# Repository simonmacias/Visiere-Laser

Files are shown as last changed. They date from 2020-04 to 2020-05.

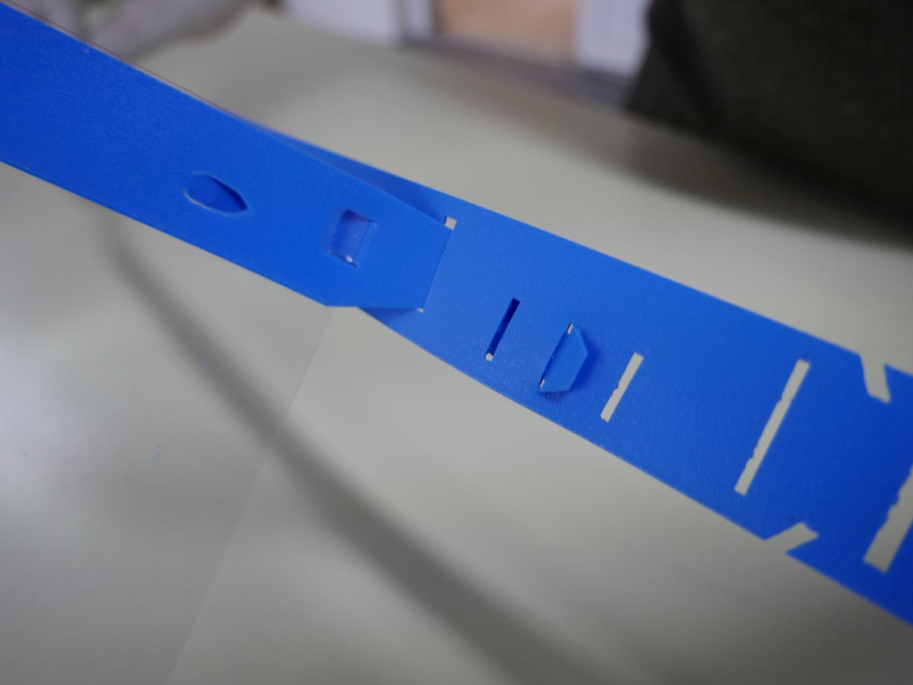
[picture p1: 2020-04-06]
VISI70/Images/2.JPG

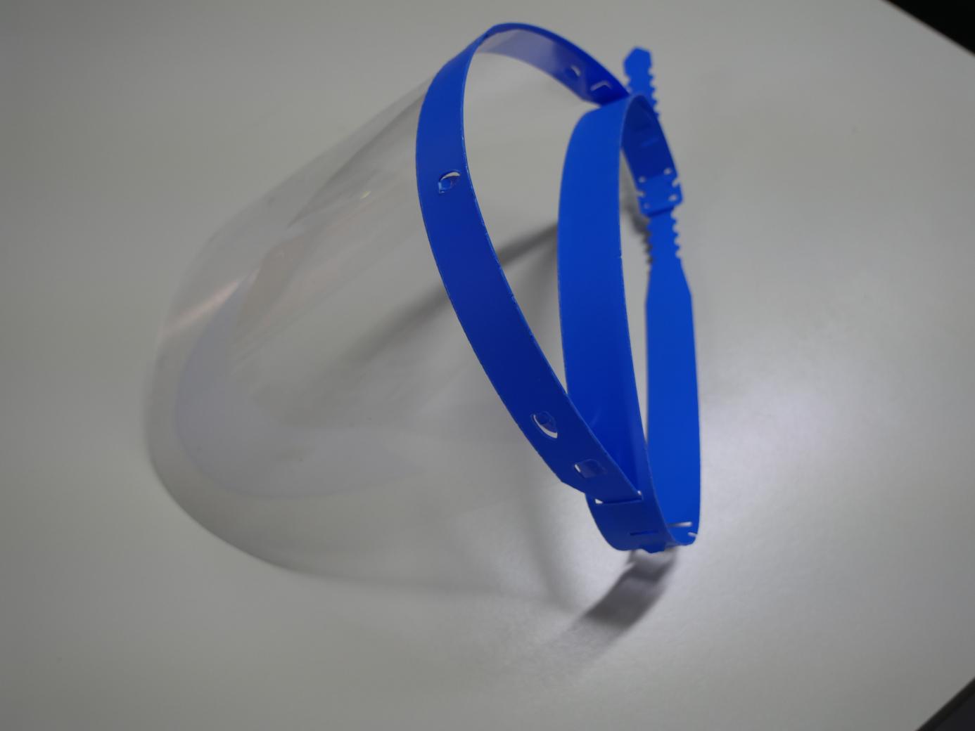
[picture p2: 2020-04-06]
VISI70/Images/4.JPG

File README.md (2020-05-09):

# Visière-Laser
Projet de visiere Anti-Projection découpée à la découpe laser pour la lutte contre le COVID-19 !  

Si vous êtes malade ou si vous présentez des symptômes, ne produisez pas !
  
Afin d'éviter la contamination des visieres pendant la production, l'assemblage et avant toute manipulation des pièces :
- Portez un masque, quelque soit son type,
- Lavez-vous les mains au savon ou avec un gel hydroalcoolique avant et régulièrement pendant l'assemblage,
- Stockez les pieces produites dans des sacs plastiques.
  
Les conseils donnés pas le Réseau Francais des Fablab sont bien rédigés, n'hésitez pas à vous y référer:
http://www.fablab.fr/coronavirus/prototypage-et-projets/article/2-visieres-de-protection-coronavirus
Pensez à la livraison et contactez les centres hospitaliers pour vous accorder sur la procédure à suivre.

Ce modèle à été validé par le CHU de Poitiers.

 ## Matériaux:
- feuille de polypropylene 0.8mm [On peut en trouver ici](https://www.polydis.fr/epages/8d7c81fe-552a-11e0-822f-000d609a287c.sf/fr_FR/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)
- feuille de transparent A4 (retroprojecteur, couverture pour reliure transparente)
 ## Outillage:
- découpe laser 390 mm * 100 mm minimum pour le modèle VISI40
- découpe laser 700 mm * 100 mm minimum pour le modèle VISI70
- perforeuse 4 trous
 ## Paramètres de coupe :
- laser CO2 60W à 100% de sa puissance, avance de 10 mm/sec
- laser CO2 130W à 100% de sa puissance, avance 40 mm/sec
 ## Note :
Ce design est aussi compatible avec des élastiques de bureautique, de couture et à garrot.
Largeur maxi : 18mm
 ## Assemblage:
- Les notices de montage sont disponibles ici :

[Notice VISI 70](https://github.com/simonmacias/Visiere-Laser/raw/master/VISI70/NoticeMontageVISI70.pdf)
- veillez à perforer les transparents bien au centre
Prix de revient : 2€ par pièce (hors temps d'assemblage)
- Tour de tête entre 52,5 et 63 cm

Ce projet est une modification de la visière ELVI10A4 crée par l'Électrolab (https://code.electrolab.fr/covid-19/visiere)
This work is licensed under a Creative Commons :
Attribution-ShareAlike 4.0 International (CC BY-SA 4.0)
https://creativecommons.org/licenses/by-sa/4.0/

Projet porté par Julien Rat et Simon Macias.
Avec l'aide de : Marie Langelier, Marcellin Dauty, Sylvain de Toillettes & Co et Thomas de Lomatia.

FINE_EQUIPE

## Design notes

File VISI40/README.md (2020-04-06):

# Visière VISI 40 
Cette visière est découpable sur une machine laser 400mm X 400mm.

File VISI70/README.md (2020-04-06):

# Visière VISI70
Cette visière est découpable sur une machine laser 700mm X 100mm.

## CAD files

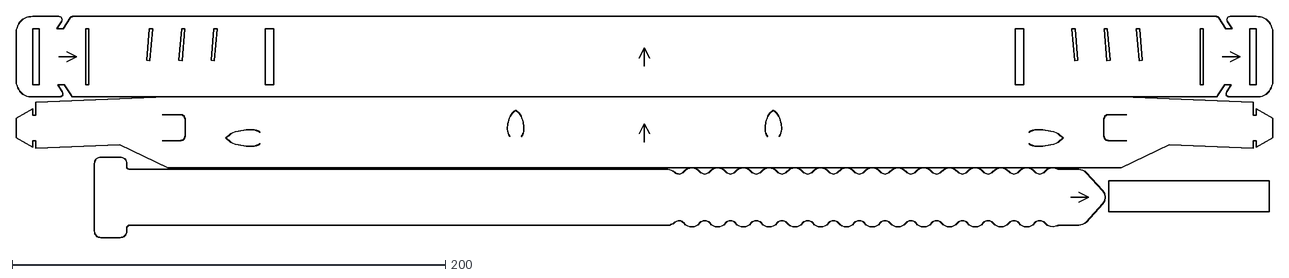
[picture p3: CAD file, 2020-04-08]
VISI40/kitVISI40.dxf
579.7 x 102.1

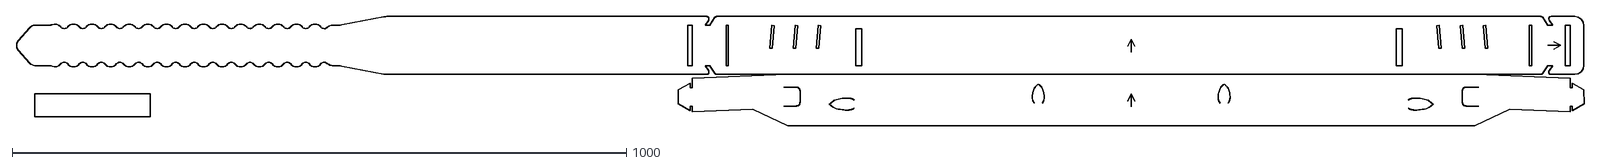
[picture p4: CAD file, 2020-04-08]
VISI70/kitVISI70.dxf
2552.8 x 177.7

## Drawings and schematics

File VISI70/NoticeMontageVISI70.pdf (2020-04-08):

# Notice de montage Visière Protection VISI 70

### Assemblage bandeau feuille avec transparent

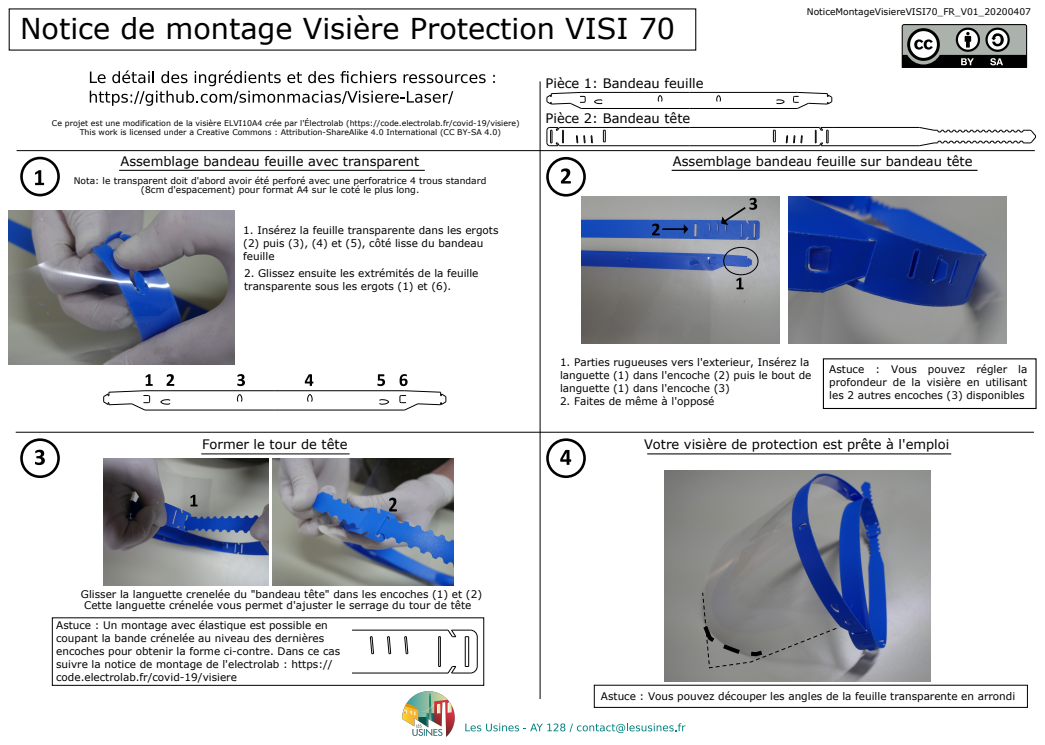
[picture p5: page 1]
NoticeMontageVisiereVISI70_FR_V01_20200407

Pièce 1: Bandeau feuille

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

Pièce 2: Bandeau tête

Assemblage bandeau feuille sur bandeau tête

Nota: le transparent doit d'abord avoir été perforé avec une perforatrice 4 trous standard

(8cm d'espacement) pour format A4 sur le coté le plus long.

1. Insérez la feuille transparente dans les ergots
(2) puis (3), (4) et (5), côté lisse du bandeau
feuille
2. Glissez ensuite les extrémités de la feuille
transparente sous les ergots (1) et (6).

1. Parties rugueuses vers l'exterieur, Insérez la
languette (1) dans l'encoche (2) puis le bout de
languette (1) dans l'encoche (3)
2. Faites de même à l'opposé

Astuce : Vous pouvez régler la
profondeur de la visière en utilisant
les 2 autres encoches (3) disponibles

Former le tour de tête

Votre visière de protection est prête à l'emploi

Glisser la languette crenelée du "bandeau tête" dans les encoches (1) et (2)
Cette languette crénelée vous permet d'ajuster le serrage du tour de tête
Astuce : Un montage avec élastique est possible en
coupant la bande crénelée au niveau des dernières
encoches pour obtenir la forme ci-contre. Dans ce cas
suivre la notice de montage de l'electrolab : https://
code.electrolab.fr/covid-19/visiere

Astuce : Vous pouvez découper les angles de la feuille transparente en arrondi

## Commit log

2020-04-05 ajout des cotes
    [#piece_1.dxf]
2020-04-08 Update kitVISI40.svg
    Ajout de congés pour eviter de trouer les gants avec les angles saillants
